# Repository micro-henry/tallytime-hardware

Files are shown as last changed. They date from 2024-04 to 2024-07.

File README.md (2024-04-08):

<picture>
  <source media="(prefers-color-scheme: dark)" srcset="https://www.uhenry.com/assets/logo-tallytime-full-white.svg">
  MicroHenry Tallytime Logo
</picture>

# Tallytime (Hardware)

An open-source low-cost Tally & Timecode device, powered by RP2040 & LoRa

> [!NOTE]
> This project is WIP and is ongoing active development, expect breaking changes and modifications

## Features

- [ ]  LTC Timecode jam & generation
- [ ]  Wireless sync through LoRa modem
- [ ]  Direct syncing through raw bitstream
- [ ]  Microphone passthrough
- [ ]  Encoder & OLED screen
- [ ]  USB-C & battery charging

## Images

> Top
> Top of PCB

> Bottom
> Bottom of PCB

PCB renders generated with a modified version (custom fonts) of [linalinn/kicad-render](https://github.com/linalinn/kicad-render)

## Authors

- [@Kelvin-Ziqi-Zhao](https://www.github.com/Kelvin-Ziqi-Zhao)
- [@Treeezheng](https://www.github.com/Treeezheng)
- [@Arom1a](https://www.github.com/Arom1a)
- [@plushugh](https://www.github.com/plushugh)

## License

[CERN-OHL-S-2.0](https://ohwr.org/cern_ohl_s_v2.txt)

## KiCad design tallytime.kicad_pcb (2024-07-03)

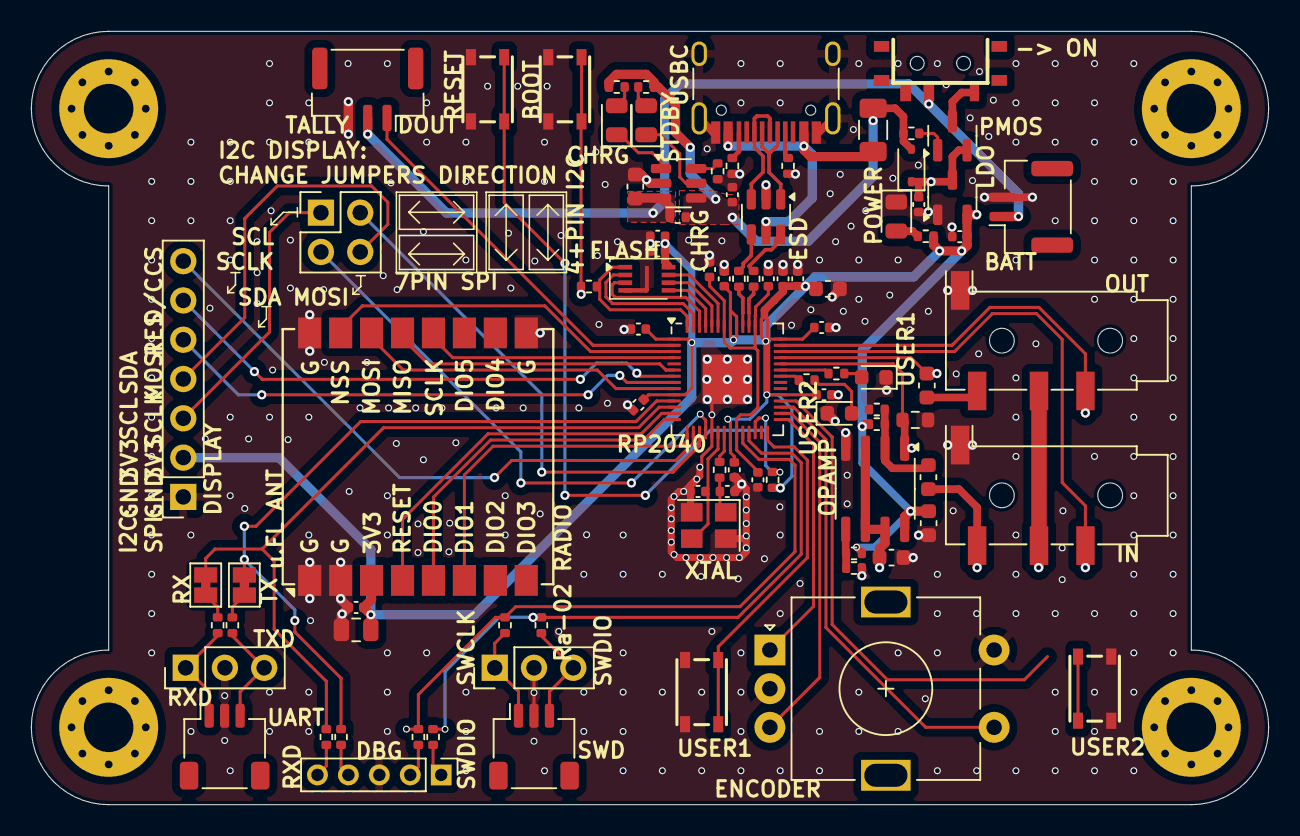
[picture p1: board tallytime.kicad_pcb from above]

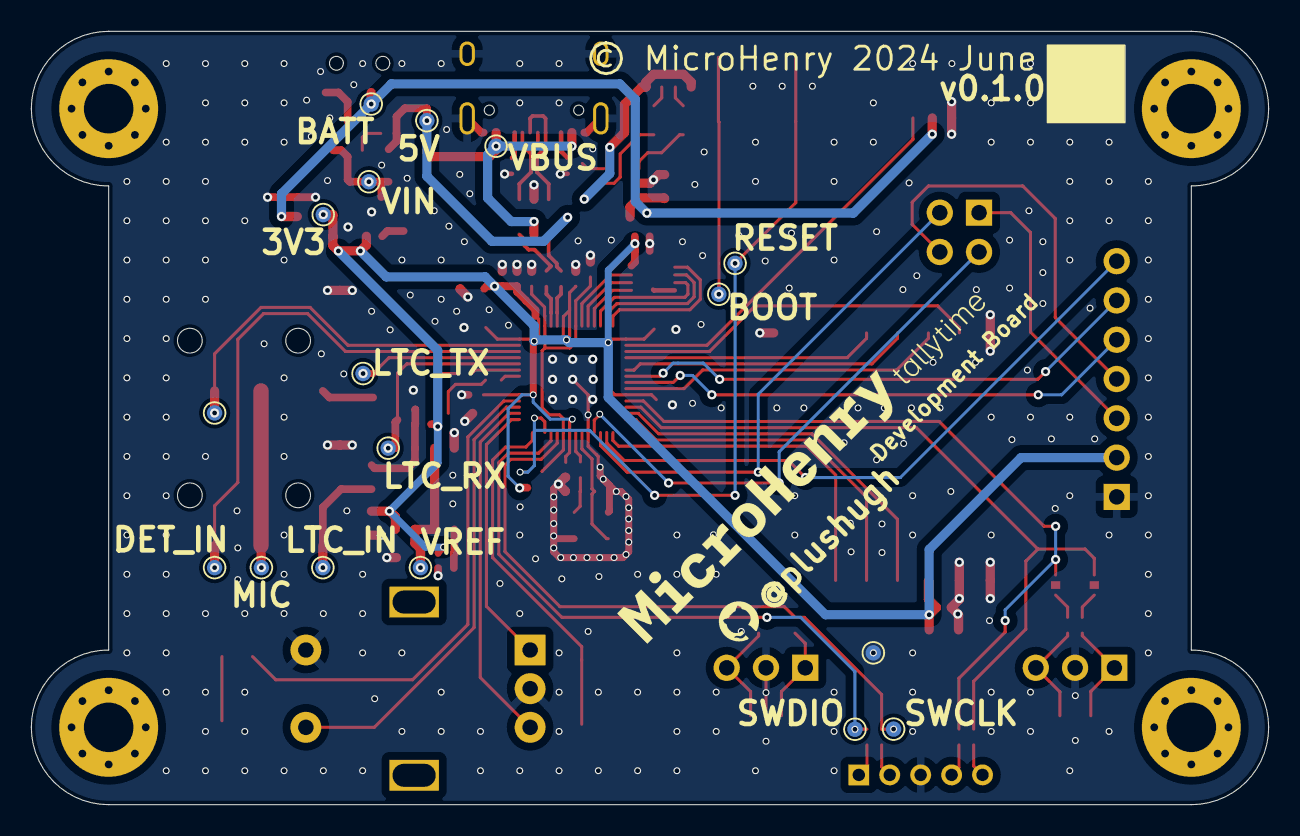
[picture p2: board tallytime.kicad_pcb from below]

Board: 4 copper layers, 80.0 x 50.0 mm, 111 parts (17 on the bottom side), 82 nets.

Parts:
C1, C2, C3, C4, C5, C6, C7, C8, C9, C14, C18: 100n; C_0402_1005Metric
C10, C19, C20, C21, C22, C25: 10u; C_0603_1608Metric
C11, C12, C23, C24, C26: 1u; C_0402_1005Metric
C13: 2.2u; C_0402_1005Metric
C15, C16: 33p; C_0402_1005Metric
C17: 22u; C_0805_2012Metric
D1: USERLED1; LED_0603_1608Metric
D2: USERLED2; LED_0603_1608Metric
D3: 1N5819WS; D_SOD-323
D4, D6: RED; LED_0805_2012Metric
D5: GREEN; LED_0805_2012Metric
F1: 1.5A; Fuse_1206_3216Metric
H1, H2, H3, H4: MountingHole_Pad; MountingHole_3.2mm_M3_Pad_Via
J1: USB_C_Receptacle_USB2.0_16P; USB_C_Receptacle_HRO_TYPE-C-31-M-12
J2: SWD; PinHeader_1x03_P2.54mm_Vertical
J3, J6: SM03B-SRSS-TB; JST_SH_SM03B-SRSS-TB_1x03-1MP_P1.00mm_Horizontal
J4: 5PIN HOLES; PinHeader_1x05_P2.00mm_Vertical
J5: UART; PinHeader_1x03_P2.54mm_Vertical
J7, J8: TRRS Out; Jack_3.5mm_KoreanHropartsElec_PJ-320D-4A_Horizontal
J9: Conn_02x02_Counter_Clockwise; PinHeader_2x02_P2.54mm_Vertical
J10: OLED DISPLAY; PinSocket_1x07_P2.54mm_Vertical
J12: BATT; JST_GH_SM02B-GHS-TB_1x02-1MP_P1.25mm_Horizontal
J13: TALLY LIGHT; JST_GH_SM03B-GHS-TB_1x03-1MP_P1.25mm_Horizontal
JP1: UART_RX; SolderJumper-2_P1.3mm_Bridged_Pad1.0x1.5mm
JP2: UART_TX; SolderJumper-2_P1.3mm_Bridged_Pad1.0x1.5mm
Q1: AO3401A; SOT-23
R1, R2, R3: 1k; R_0402_1005Metric
R4, R5, R16, R17, R23, R24, R25, R26, R27: 5k1; R_0402_1005Metric
R6, R7: 22; R_0402_1005Metric
R8, R9, R10, R11, R12, R13, R14, R15: 100; R_0402_1005Metric
R18, R19, R20, R22: 10k; R_0402_1005Metric
R21: 150k; R_0603_1608Metric
R28: 2k; R_0402_1005Metric
SW1, SW2, SW4, SW5: SKRPACE010
SW3: EC11; RotaryEncoder_Alps_EC11E-Switch_Vertical_H20mm
SW6: SW_SPDT; SW-SMD_3P-P1.50_L2.7-W6.6
TP1: VBUS; TestPoint_Pad_D1.0mm
TP2: SWCLK; TestPoint_Pad_D1.0mm
TP3: SWDIO; TestPoint_Pad_D1.0mm
TP4: BOOT; TestPoint_Pad_D1.0mm
TP5: RESET; TestPoint_Pad_D1.0mm
TP6: VREF; TestPoint_Pad_D1.0mm
TP7: LTC_RX; TestPoint_Pad_D1.0mm
TP8: LTC_TX; TestPoint_Pad_D1.0mm
TP9: LTC_IN; TestPoint_Pad_D1.0mm
TP10: MIC; TestPoint_Pad_D1.0mm
TP11: DET_IN; TestPoint_Pad_D1.0mm
TP12: DET_OUT; TestPoint_Pad_D1.0mm
TP13: BATT; TestPoint_Pad_D1.0mm
TP14: VIN; TestPoint_Pad_D1.0mm
TP15: 3V3; TestPoint_Pad_D1.0mm
TP16: 5V; TestPoint_Pad_D1.0mm
TP17: GND; TestPoint_Pad_D1.0mm
U1: W25Q16JVUXIQ; SON50P300X200X60-9N
U2: RP2040; QFN-56-1EP_7x7mm_P0.4mm_EP3.2x3.2mm
U3: USBLC6-2SC6; SOT-23-6
U4: Ai-Thinker-Ra-02; Ai-Thinker-Ra-01-LoRa
U5: LM358; SOP-8_3.9x4.9mm_P1.27mm
U6: XC6206P332MR; SOT-23-3
U7: TP4057; SOT-23-6
Y1: 12MHz +-10ppm 20pF; Crystal_SMD_3225-4Pin_3.2x2.5mm

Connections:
+1V1: C1.1, C2.1, C11.1, U2.23 (DVDD), U2.45 (VREG_VOUT), U2.50 (DVDD)
+3V3: C3.1, C4.1, C5.1, C6.1, C7.1, C8.1, C9.1, C10.1, C12.1, C13.1, C14.1, C17.1, C18.1, C19.1, C24.1, J10.2, R1.1, R18.1, R20.1, R24.1, TP15.1, U1.8 (VCC), U2.1 (IOVDD), U2.10 (IOVDD), U2.22 (IOVDD), U2.33 (IOVDD), U2.42 (IOVDD), U2.43 (ADC_AVDD), U2.44 (VREG_IN), U2.48 (USB_VDD), U2.49 (IOVDD), U4.3 (VDD), U5.8 (V+), U6.2 (VO)
+5V: C26.1, D3.2 (A), F1.2, R23.1, R25.1, R26.1, R27.1, TP16.1, U7.4 (VCC)
+BATT: C25.1, J12.1, J13.2, R27.2, SW6.2 (B), TP13.1, U7.3 (BAT)
+VIN: C23.1, D3.1 (K), Q1.2 (S), TP14.1, U6.3 (VI)
/Debug/3PIN_SWD_SWCLK: J2.1, J3.1, R9.1
/Debug/3PIN_SWD_SWDIO: J2.3, J3.3, R11.1
/Debug/3PIN_UART_RX: J5.1, J6.1, R14.1
/Debug/3PIN_UART_TX: J5.3, J6.3, R15.1
/Debug/5PIN_SWD_SWCLK: J4.2, R10.1
/Debug/5PIN_SWD_SWDIO: J4.1, R8.1
/Debug/5PIN_UART_RX: J4.5, R13.1
/Debug/5PIN_UART_TX: J4.4, R12.1
/Debug/ENCODER_A: SW3.A, U2.29 (GPIO18)
/Debug/ENCODER_B: SW3.B, U2.30 (GPIO19)
/Debug/ENCODER_SW: SW3.S1, U2.31 (GPIO20)
/Debug/JMP_UART_RX: JP1.2 (B), R14.2
/Debug/JMP_UART_TX: JP2.2 (B), R15.2
/Debug/SWCLK: R9.2, R10.2, TP2.1, U2.24 (SWCLK)
/Debug/SWDIO: R8.2, R11.2, TP3.1, U2.25 (SWD)
/Debug/TALLY: J13.1, U2.2 (GPIO0)
/Debug/UART_RX: JP1.1 (A), R13.2, U2.12 (GPIO9)
/Debug/UART_TX: JP2.1 (A), R12.2, U2.11 (GPIO8)
/Debug/USERLED1: R16.1, U2.37 (GPIO25)
/Debug/USERLED1_K: D1.2 (A), R16.2
/Debug/USERLED2: R17.1, U2.36 (GPIO24)
/Debug/USERLED2_K: D2.2 (A), R17.2
/Debug/USERSW1: SW2.1, SW2.3, U2.28 (GPIO17)
/Debug/USERSW2: SW5.1, SW5.3, U2.32 (GPIO21)
/Debug/~BOOT: R2.1, SW1.1, SW1.3, TP4.1
/Debug/~RESET: R1.2, SW4.1, SW4.3, TP5.1, U2.26 (RUN)
/Display/CS: J10.7, U2.16 (GPIO13)
/Display/D/C: J10.6, U2.7 (GPIO5)
/Display/MOSI_SDA: J9.4, J10.4
/Display/RES: J10.5, U2.8 (GPIO6)
/Display/SCLK_SCL: J9.1, J10.3
/Display/SCL_MOSI: J9.3, U2.18 (GPIO15)
/Display/SDA_SCLK: J9.2, U2.17 (GPIO14)
/MCU/GPIO1: U2.3 (GPIO1), U4.15 (~NSS)
/MCU/GPIO2: U2.4 (GPIO2), U4.12 (SCK)
/MCU/GPIO4: U2.6 (GPIO4), U4.13 (MISO)
/MCU/GPIO7: U2.9 (GPIO7), U4.14 (MOSI)
/MCU/GPIO10: U2.13 (GPIO10), U4.4 (~RESET)
/MCU/GPIO11: U2.14 (GPIO11), U4.5 (DIO0)
/MCU/GPIO12: U2.15 (GPIO12), U4.6 (DIO1)
/MCU/GPIO26_ADC0: R21.1, TP7.1, U2.38 (GPIO26_ADC0), U5.1
/MCU/GPIO27_ADC1: C22.1, TP8.1, U2.39 (GPIO27_ADC1)
/MCU/GPIO28_ADC2: J7.R2, TP11.1, U2.40 (GPIO28_ADC2)
/MCU/GPIO29_ADC3: J8.R2, TP12.1, U2.41 (GPIO29_ADC3)
/MCU/QSPI_SCLK: U1.6 (CLK), U2.52 (QSPI_SCLK)
/MCU/QSPI_SD0: U1.5 (DI_(IO0)), U2.53 (QSPI_SD0)
/MCU/QSPI_SD1: U1.2 (DO_(IO1)), U2.55 (QSPI_SD1)
/MCU/QSPI_SD2: U1.3 (~WP_(IO2)), U2.54 (QSPI_SD2)
/MCU/QSPI_SD3: U1.7 (~HOLD_OR_RESET_(IO3)), U2.51 (QSPI_SD3)
/MCU/QSPI_SS: R2.2, U1.1 (~CS), U2.56 (QSPI_SS)
/MCU/USB_D+: R7.2, U2.47 (USB_DP)
/MCU/USB_D-: R6.2, U2.46 (USB_DM)
/MCU/XIN: C15.2, U2.20 (XIN), Y1.3
/MCU/XOUT: R3.2, U2.21 (XOUT)
/MCU/XTAL_XOUT: C16.2, R3.1, Y1.1
/Power/BATT_SW: Q1.3 (D), SW6.1 (A)
/Power/MOS_BIAS: Q1.1 (G), R23.2
/Power/POWER_LED_K: D4.2 (A), R24.2
/Timecode/LTC_IN: C21.1, J7.T, TP9.1
/Timecode/LTC_OUT: C22.2, J8.T
/Timecode/MIC_PASSTHROUGH: J7.R1, J8.R1, TP10.1
/Timecode/OPAMP_A_N: C21.2, R20.2, R22.1, U5.2 (-)
/Timecode/OPAMP_B_P: R18.2, R19.1, U5.5 (+)
/Timecode/VREF: C20.1, TP6.1, U5.3 (+), U5.6 (-), U5.7
/USB/USBD+: J1.A6 (D+), J1.B6 (D+), U3.3 (I/O2)
/USB/USBD-: J1.A7 (D-), J1.B7 (D-), U3.1 (I/O1)
/USB/USBESD+: R7.1, U3.4 (I/O2)
/USB/USBESD-: R6.1, U3.6 (I/O1)
/USB/USB_CC1: J1.A5 (CC1), R4.1
/USB/USB_CC2: J1.B5 (CC2), R5.1
GND: C1.2, C2.2, C3.2, C4.2, C5.2, C6.2, C7.2, C8.2, C9.2, C10.2, C11.2, C12.2, C13.2, C14.2, C15.1, C16.1, C17.2, C18.2, C19.2, C20.2, C23.2, C24.2, C25.2, C26.2, D1.1 (K), D2.1 (K), D4.1 (K), J1.A1 (GND), J1.A12 (GND), J1.B1 (GND), J1.B12 (GND), J1.S1 (SHIELD), J2.2, J3.2, J4.3, J5.2, J6.2, J7.S, J8.S, J10.1, J12.2, J13.3, R4.2, R5.2, R19.2, R21.2, R22.2, R28.2, SW1.2, SW1.4, SW2.2, SW2.4, SW3.C, SW3.S2, SW4.2, SW4.4, SW5.2, SW5.4, TP17.1, U1.4 (GND), U1.9 (EP), U2.19 (TESTEN), U2.57 (GND), U3.2 (GND), U4.1 (GND), U4.2 (GND), U4.9 (GND), U4.16 (GND), U5.4 (V-), U6.1 (GND), U7.2 (GND), Y1.2, Y1.4
unnamed: D5.2 (A), R25.2
unnamed: D5.1 (K), U7.5 (~STDBY)
unnamed: D6.2 (A), R26.2
unnamed: D6.1 (K), U7.1 (~CHRG)
unnamed: R28.1, U7.6 (PROG)
VBUS: F1.1, J1.A4 (VBUS), J1.A9 (VBUS), J1.B4 (VBUS), J1.B9 (VBUS), TP1.1, U3.5 (VBUS)

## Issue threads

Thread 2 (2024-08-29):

Why 4 layers?

picli3, 2024-08-29:
I see that you are using 4 layers but you don't do anything with that, you do it through the USB, but it is so close that it doesn't affect. Otherwise I don't see anything else!

plushugh, 2024-09-05:
IMHO 4L is not really that much more expensive, (10CNY extra in china (around USD$1.5) for 5 boards) we're doing some RF traces in the next rev as well so it certainly would be better with the reference planes, generally having better EMI performance is worth the tiny cost for 4L

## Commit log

2024-04-08 init: add files via upload
    [crystal.kicad_sch, display.kicad_sch, flash.kicad_sch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]
2024-04-08 actions: Create pcb_image.yml
2024-04-08 actions(pcb_image): include fonts
2024-04-08 actions(pcb_image): update pages actions
2024-04-08 actions(pcb_image): fix inter font URL
2024-04-08 actions(pcb_image): use fork of renderer with fonts
2024-04-08 actions(pcb_image): fix deploy action version
2024-04-12 feat: optimizations
    [interfaces.kicad_sch, mcu.kicad_sch, power.kicad_sch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]
2024-04-13 feat: ESD optimizations
    [tallytime.kicad_pcb, usb.kicad_sch]

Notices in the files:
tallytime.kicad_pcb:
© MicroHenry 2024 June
